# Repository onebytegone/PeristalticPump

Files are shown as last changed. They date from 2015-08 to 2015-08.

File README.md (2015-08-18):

# Peristaltic Pump

I have been wanting an inexpensive peristaltic pump for a while. This is a basic mechanical engineering project to design and build one.

## Requirements

  * Cost of goods to be under $8 (This is for major costs, minor hardware does not count towards this)
  * 3D printing acceptable for manufacturing
  * Be able to pump at least 250ml per minute (Accuracy is preferred over speed)
  * Use common hardware (Consumer friendly retailer, e.g. [SparkFun](http://sparkfun.com)/[Pololu](http://pololu.com), or local hardware store)
  * Support for rotation tracking is not mandatory
  * Should operate in the range of 3v-12v (Support for the entire rage is not necessary)
  * Supports fluids the about the viscosity of water
  * Can be made food safe

## Licence

This work is licensed under a [Creative Commons Attribution-ShareAlike 4.0 International License](http://creativecommons.org/licenses/by-sa/4.0/)

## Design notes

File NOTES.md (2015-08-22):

# Development Notes

## v0.2

  * Silicone tubing work much better than vinyl tubing
  * For pumping water, the hose needs to be completely compressed to create the needed suction
  * Rollers for the propeller are required
  * A couple extra mm of height for the compresstion channel may be helpful
  * A retaing rail to prevent the hose from walking out would be an improvement
  * The back wall needs to extend further along the perimeter. This is to help with keeping a constant suction
  * It might be possible to only have two arms on the propeller instead of 4

## v0.1

  * Vinyl tubing, such as aquarium air hose, is too stiff for this purpose
  * Without rollers on the propeller tips, a lot of force is needed to rotate the propller. This may just be caused by using vinyl tubing.

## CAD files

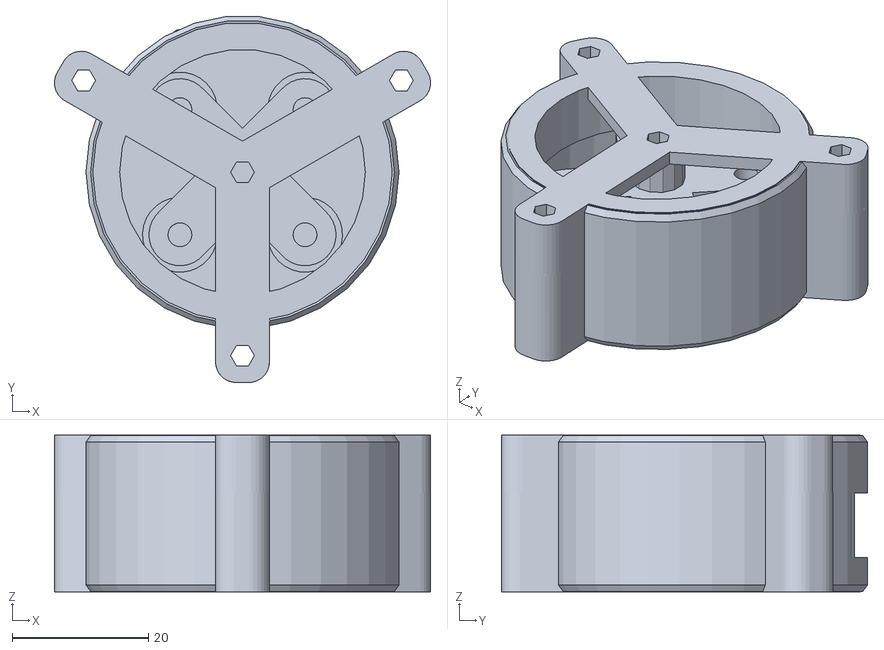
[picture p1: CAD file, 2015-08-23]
exports/assembled.stl
55.3 x 53.8 x 23.0

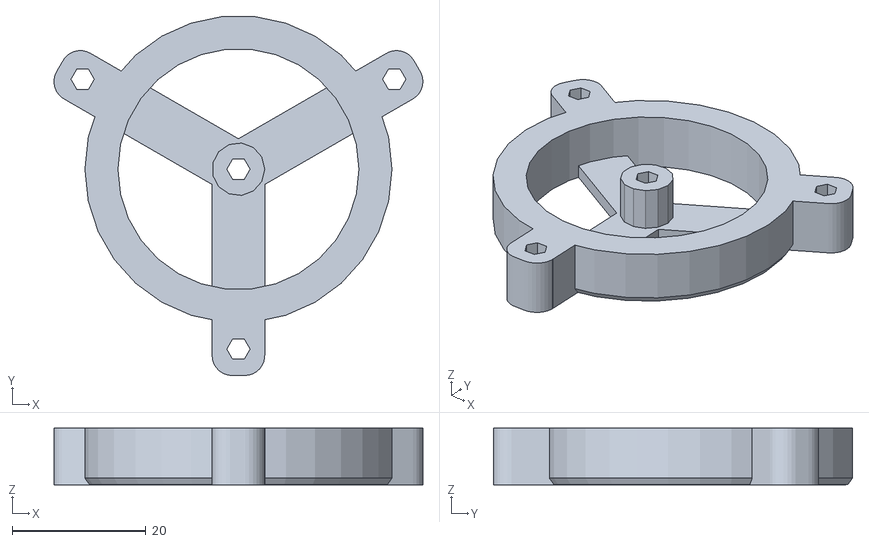
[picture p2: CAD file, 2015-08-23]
exports/outer_shell_cap.stl
55.3 x 53.8 x 8.50

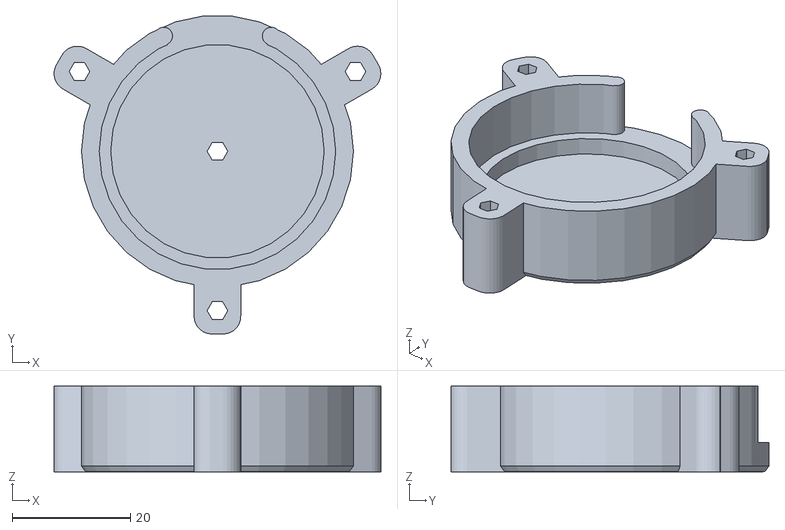
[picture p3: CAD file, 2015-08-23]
exports/outer_shell.stl
55.3 x 53.8 x 14.5

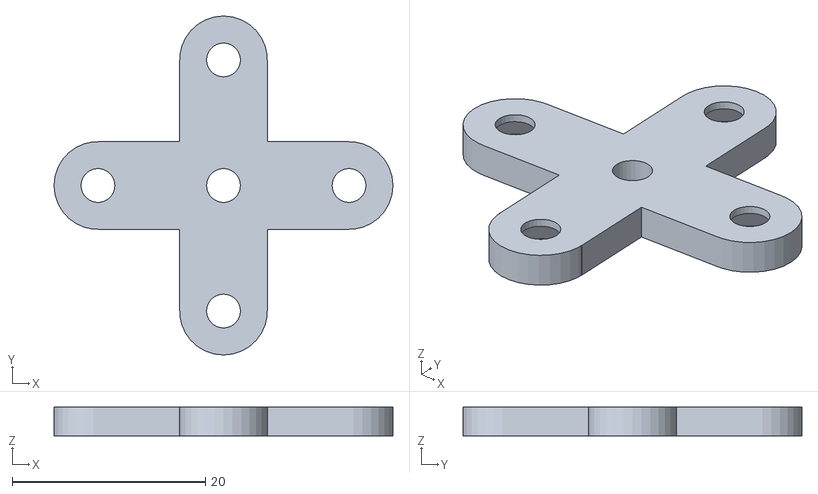
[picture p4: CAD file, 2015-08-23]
exports/propeller_retainer.stl
35.1 x 35.1 x 3.00

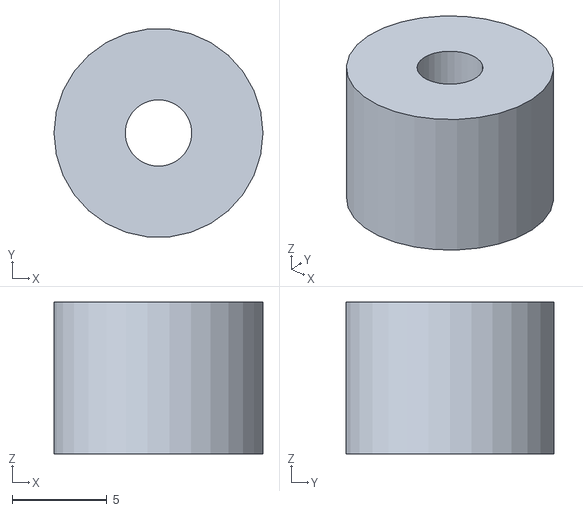
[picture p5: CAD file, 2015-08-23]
exports/roller.stl
11.0 x 10.9 x 8.00

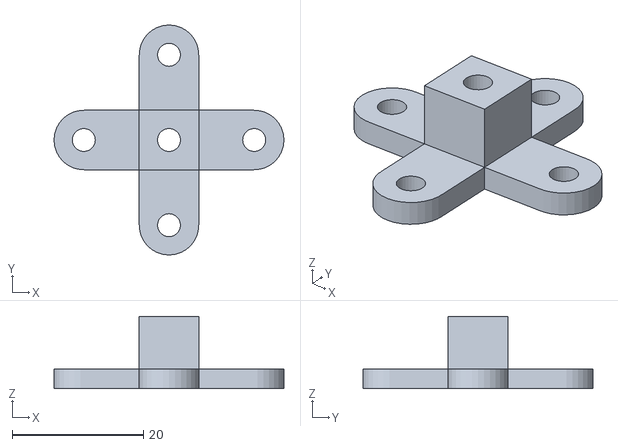
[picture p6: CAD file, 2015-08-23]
exports/propeller.stl
35.1 x 35.1 x 11.0

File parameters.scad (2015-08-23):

/**
 * These are all of the shared variables that
 * are needed for the pump.
 *
 * Created 2015-08-18 by Ethan Smith
 */


/*------------------------
 * HARDWARE
 *----------------------*/

/**
 * Sizing for a #6 bolt or equivalent
 */
SmallBoltDiameter = 3.5;
SmallBoltCountersinkEndDiameter = 7.3;
SmallBoltCountersinkDepth = 2.3;


/*------------------------
 * FIXED MODEL SIZES
 *----------------------*/

/**
 * Outside diameter for the hose/tubing
 */
HoseOD = 5;

/**
 * Size to which the hose should be compressed to
 */
HoseCompressedThickness = 1.5;

/**
 * The basic wall thickness to abide by
 */
WallThickness = 1.2;

/**
 * The distance from center to center of
 * where the tubing will reside
 */
PumpDiameter = 35;

/**
 * Thickness for the bottom of the outer shell
 */
ShellBaseThickness = 2;

/**
 * Height for the channel supporting the hose
 */
ChannelHeight = 9.5;

/**
 * Thickness for the back wall for the outer shell
 */
ShellLipThickness = 3;

/**
 * Angle used to set the length of the gap in
 * the wall for the tubing to come out
 */
ShellCutoutAngle = 50;

/**
 * The radius for the the outer edges for the shell
 */
ShellPerimeterEdgeRadius = 1;

/**
 * The extra between the propeller supports and the shell
 */
ShellPropellerBuffer = 0.5;

/**
 * Mounting tab bolt size
 */
MountingTabBoltDiameter = SmallBoltDiameter;

/**
 * Wall thickness for mounting tabs
 */
MountingTabWallThickness = 2.2;

/**
 * Angle for mounting tabs by gap
 */
SecondaryMountingTabAngle = 120;

/**
 * Diameter for the axel
 */
AxelDiameter = SmallBoltDiameter;

/**
 * General corner radius
 */
CornerRadius = 3;

/**
 * Bolt to hold roller
 */
RollerBolt = SmallBoltDiameter;
RollerBoltCountersinkEndDiameter = SmallBoltCountersinkEndDiameter;
RollerBoltCountersinkDepth = SmallBoltCountersinkDepth;

/**
 * Outside diameter for roller
 */
RollerOD = 11;

/**
 * Height/Thickness for roller
 */
RollerThickness = 8;

/**
 * $fn used for the roller bolt and outside
 */
RollerSmooth = 30;

/**
 * The thickness for the propeller arms
 */
PropellerBacking = 3;

/**
 * $fn used for the propeller
 */
PropellerSmooth = 30;

/**
 * The wall thickness for the propeller
 */
PropellerMinWall = 2.8;

/**
 * The thickness for the propeller retaining plate
 */
PropellerSupport = 3;

/**
 * Height for the cap's lip
 */
ShellCapExtraLip = 6.5;

/**
 * The general $fn to be used for edge smoothing
 */
EdgeSmooth = 20;


/*------------------------
 * RENDERING
 *----------------------*/

/**
 * This helps prevent non-maniford meshes
 */
Overlap = 0.1;


/*------------------------
 * CALCULATED
 *----------------------*/

/**
 * Distance for the outer shell of the pump
 *
 * Sizing:
 * | WALL | 1/2 of HOSE |  PumpDiameter | 1/2 of HOSE | WALL |
 */
OuterHoseEdge = PumpDiameter + HoseOD;
OuterWidth = OuterHoseEdge + (ShellLipThickness * 2);

/**
 * Thickness for the shell that includes outer wall and
 * the inset for the propeller
 */
ShellCoreThickness = ShellBaseThickness + PropellerSupport;

/**
 * Entire height for the outer shell
 */
ShellTotalThickness = ShellCoreThickness + ChannelHeight;

/**
 * How far the angled cutout needs to extend
 */
ShellCutoutRadius = OuterWidth / 2 + Overlap;

/**
 * How far to the side the cutout is offset by to get
 * the correct angle opening
 */
ShellCutoutSideShift = ShellCutoutRadius * (tan(ShellCutoutAngle / 2));

/**
 * Width and Length for the mounting tab
 */
MountingTabSize = MountingTabBoltDiameter + MountingTabWallThickness * 2;

/**
 * The total length for the propeller
 */
PropellerTotalLength = OuterHoseEdge - HoseCompressedThickness * 2;

/**
 * The distance from the centers of the bolts for oppisate  for the propeller
 */
PropellerRollerDistance = PropellerTotalLength - RollerOD;

/**
 * The width for the propeller
 */
PropellerWidth = AxelDiameter + PropellerMinWall * 2;

/**
 * The thickness for the propeller
 */
PropellerCenterThickness = RollerThickness + PropellerBacking;

/**
 * Diameter for the cutout for the propeller retainer plate
 */
ShellPropellerCutoutDiameter = PropellerRollerDistance + PropellerWidth + ShellPropellerBuffer * 2;

/**
 * Total height for the shell cap
 */
ShellCapThickness = ShellCapExtraLip + ShellBaseThickness;

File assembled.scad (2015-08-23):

use <elements/outer_shell.scad>;
use <elements/propeller.scad>;
use <elements/roller.scad>;
include <parameters.scad>;

outer_shell();
translate([0, 0, ShellTotalThickness + ShellCapThickness]) rotate([180,0,180]) outer_shell_cap();
translate([0, 0, ShellBaseThickness]) rotate([0,0,45]) propeller_retainer();
translate([0, 0, ShellCoreThickness + PropellerCenterThickness]) rotate([0,0,45]) rotate([180,0]) propeller();
translate([0, 0, ShellCoreThickness + RollerThickness]) rotate([0,0,45]) translate([PropellerRollerDistance/2, 0]) rotate([180,0]) roller();
translate([0, 0, ShellCoreThickness + RollerThickness]) rotate([0,0,45]) translate([-PropellerRollerDistance/2, 0]) rotate([180,0]) roller();
translate([0, 0, ShellCoreThickness + RollerThickness]) rotate([0,0,45]) translate([0, PropellerRollerDistance/2]) rotate([180,0]) roller();
translate([0, 0, ShellCoreThickness + RollerThickness]) rotate([0,0,45]) translate([0, -PropellerRollerDistance/2]) rotate([180,0]) roller();

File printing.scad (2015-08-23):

use <elements/outer_shell.scad>;
use <elements/propeller.scad>;
use <elements/roller.scad>;

/**
 * Uncomment one at a time for single part export
 */
// outer_shell();
// outer_shell_cap();
// propeller();
// propeller_retainer();
// roller();

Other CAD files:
elements/outer_shell.scad
elements/propeller.scad
elements/roller.scad

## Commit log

2015-08-18 Added basic file structure
    [assembled.scad, outer_shell.scad, parameters.scad]
2015-08-18 Added start for outer shell
    [outer_shell.scad, parameters.scad]
2015-08-19 Added axel and tab for outer shell
    [outer_shell.scad, parameters.scad]
2015-08-19 Added propeller
    [assembled.scad, parameters.scad, propeller.scad]
2015-08-19 Moved to tab length over height
    [outer_shell.scad, parameters.scad]
2015-08-19 Added rounded corners to tab
    [outer_shell.scad, parameters.scad]
2015-08-19 Fixed using wrong variable
    [parameters.scad]
2015-08-19 Sizing adjustments
    [parameters.scad]
2015-08-19 Added print export file
    [printing.scad]
2015-08-20 Adjusted params to real world values
    [parameters.scad]
2015-08-20 Added exports for v0.1
    [outer_shell.stl, propeller.stl]
2015-08-22 Created basic roller
    [parameters.scad, printing.scad, roller.scad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]
2015-08-22 Adjusted hose compression for silicone tubing
    [parameters.scad]
2015-08-22 Abstracted bolt sizing
    [parameters.scad]
2015-08-22 Upgraded rollers with countersinking
    [parameters.scad, roller.scad, roller.stl]
2015-08-22 Upgraded propeller with rotors
    [assembled.scad, parameters.scad, propeller.scad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]
2015-08-22 Added assembled model
    [assembled.stl]
2015-08-23 Added more support wall to shell
    [assembled.stl, outer_shell.scad, outer_shell.stl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]
2015-08-23 Added propeller retainer
    [assembled.scad, assembled.stl, outer_shell.scad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]
2015-08-23 Increased channel height
    [outer_shell.stl, parameters.scad]
2015-08-23 Removed needed var
    [parameters.scad]
2015-08-23 Added tabs to shell
    [outer_shell.scad, outer_shell.stl, parameters.scad]
2015-08-23 Updated assembled model
    [assembled.stl]
2015-08-23 Thickness adjustments
    [outer_shell.stl, parameters.scad]
2015-08-23 Created cap
    [assembled.scad, assembled.stl, outer_shell.scad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]
